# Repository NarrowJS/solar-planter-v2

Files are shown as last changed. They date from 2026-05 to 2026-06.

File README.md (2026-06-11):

# Solar Planter V2
Integrates temperature, humidity, and soil moisture sensing into a single discrete plant pot and notifies you of the plant's health using LEDs and push notifications via IOT. The pot features a solar panel on the side to slowly recharge the internal battery, removing the need for recharging the device manually.
### Features
- Zigbee and Matter connectivity for low power wireless communication
- RGB Leds for notification
- Easily removable plant pot via magnets for a modular design
- Removable temperature and humidity sensor module

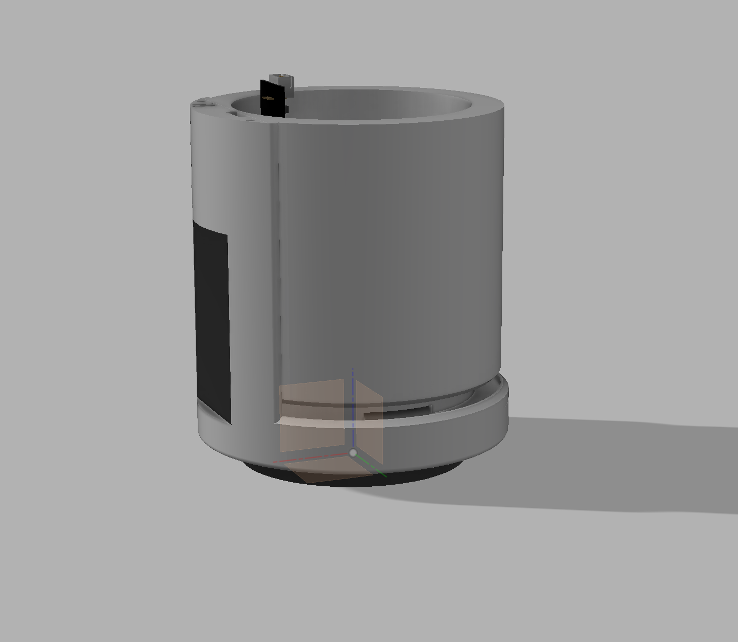
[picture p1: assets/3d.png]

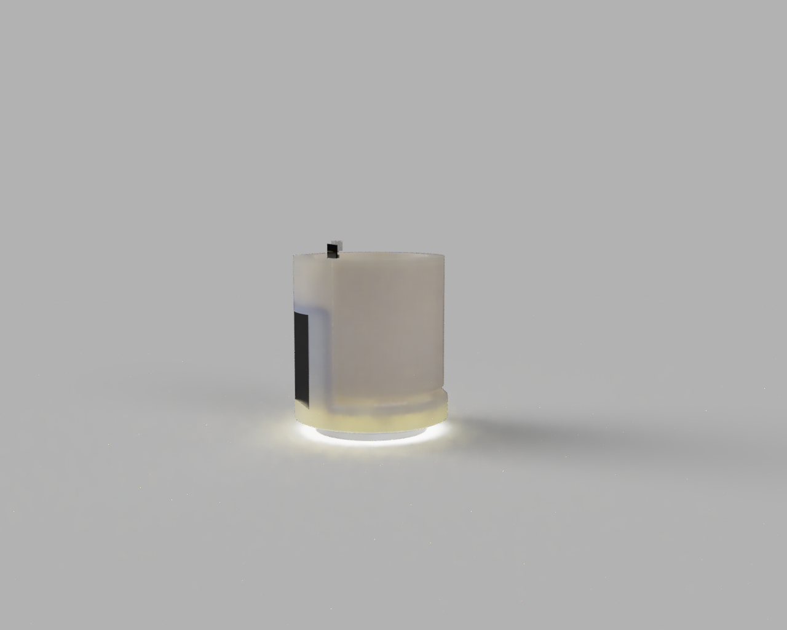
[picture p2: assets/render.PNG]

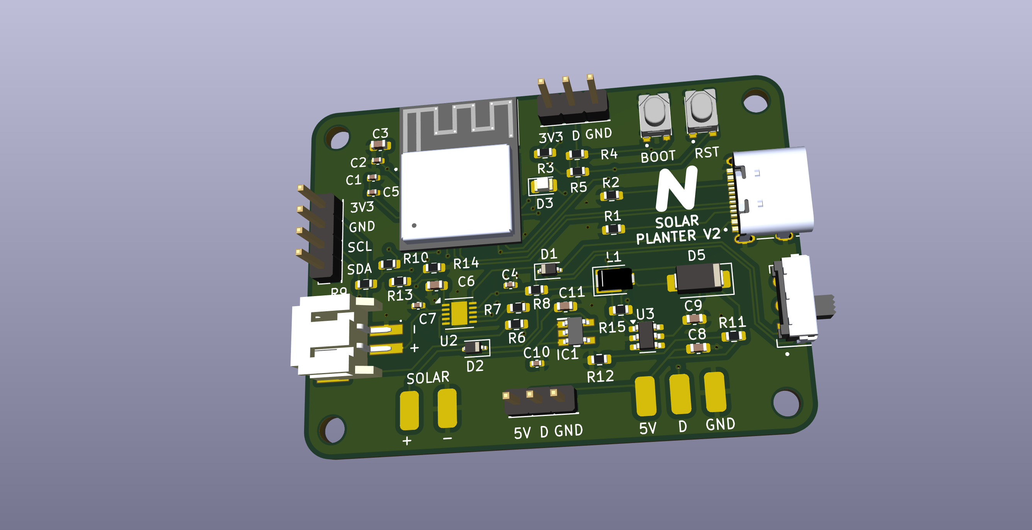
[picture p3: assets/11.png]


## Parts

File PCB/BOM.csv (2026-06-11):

Id | Designator | Footprint | Quantity | Designation | Part # | Link
1 | S1 | SW_EG1247 | 1 | EG1247 | C431548 | https://www.lcsc.com/product-detail/C431548.html
2 | D3 | LED_0805_2012Metric | 1 | CHARGE LED | C19273154 | https://www.lcsc.com/product-detail/C19273154.html
3 | C4,C5,C1,C2 | C_0402_1005Metric | 4 | 100nF | C60474 | https://www.lcsc.com/product-detail/C60474.html
4 | U1 | XCVR_ESP32-C6-MINI-1-H4 | 1 | ESP32-C6-MINI-1-H4 | C6553337 | https://www.lcsc.com/product-detail/C6553337.html
5 | 3V3 | PinHeader_1x01_P2.54mm_Vertical | 1 | MOISTURE_VCC
6 | GND | SolderWirePad_1x01_SMD_1x2mm | 1 | LED_GND
7 | R3,R4,R5,R10,R15,R8,R9,R7 | R_0603_1608Metric | 8 | 10k | C95204 | https://www.lcsc.com/product-detail/C95204.html
8 | C8,C9 | C_0603_1608Metric | 2 | 22uF | C86295 | https://www.lcsc.com/product-detail/C86295.html
9 | R6,R12 | R_0603_1608Metric | 2 | 1k | C5362357 | https://www.lcsc.com/product-detail/C5362357.html
10 | R2,R1 | R_0603_1608Metric | 2 | 5k1 | C2907044 | https://www.lcsc.com/product-detail/C2907044.html
11 | D | PinHeader_1x01_P2.54mm_Vertical | 1 | MOISTURE_DATA
12 | 5V | PinHeader_1x01_P2.54mm_Vertical | 1 | TEMP_VCC
13 | BOOT,RST | SW_PTS810_SJM_250_SMTR_LFS | 2 | PTS810_SJM_250_SMTR_LFS | C116501 | https://www.lcsc.com/product-detail/C116501.html
14 | C6,C11,C3 | C_0603_1608Metric | 3 | 10uF | C19702 | https://www.lcsc.com/product-detail/C19702.html
15 | D5 | D_SMA | 1 | SS34 | C908680 | https://www.lcsc.com/product-detail/C908680.html
16 | GND | PinHeader_1x01_P2.54mm_Vertical | 1 | TEMP_GND
17 | U3 | SOT-23-6 | 1 | MT3608 | C84817 | https://www.lcsc.com/product-detail/C84817.html
18 | C7,C10 | C_0402_1005Metric | 2 | 1uF | C29266 | https://www.lcsc.com/product-detail/C29266.html
19 | IC1 | SOT94P280X100-5N | 1 | RT9080-33GJ5 | C841192 | https://www.lcsc.com/product-detail/C841192.html
20 | + - | JST_S2B-PH-SM4-TB | 1 | S2B-PH-SM4-TB | C295747 | https://www.lcsc.com/product-detail/C295747.html
21 | D2,D1 | D_SOD-323 | 2 | 1N5819WS | C191023 | https://www.lcsc.com/product-detail/C191023.html
22 | J1 | HRO_TYPE-C-31-M-12 | 1 | TYPE-C-31-M-12 | C165948 | https://www.lcsc.com/product-detail/C165948.html
23 | + | SolderWirePad_1x01_SMD_1x2mm | 1 | +SOLAR
24 | 3V3 | PinHeader_1x01_P2.54mm_Vertical | 1 | 3V3
25 | GND | PinHeader_1x01_P2.54mm_Vertical | 1 | MOISTURE_GND
26 | SDA | PinHeader_1x01_P2.54mm_Vertical | 1 | SDA
27 | L1 | D_SMP_DO-220AA | 1 | CD32 | C41408473 | https://www.lcsc.com/product-detail/C41408473.html
28 | GND | PinHeader_1x01_P2.54mm_Vertical | 1 | LED_GND
29 | R11 | R_0603_1608Metric | 1 | 7K5 | C23234 | https://www.lcsc.com/product-detail/C23234.html
30 | D | SolderWirePad_1x01_SMD_1x2mm | 1 | LED_DATA
31 | 5V | SolderWirePad_1x01_SMD_1x2mm | 1 | LED_VCC
32 | SCL | PinHeader_1x01_P2.54mm_Vertical | 1 | SCL
33 | - | SolderWirePad_1x01_SMD_1x2mm | 1 | SOLAR-
34 | R14 | R_0603_1608Metric | 1 | 100k | C14675 | https://www.lcsc.com/product-detail/C14675.html
35 | U2 | DFN-10-1EP_3x3mm_P0.5mm_EP1.7x2.5mm | 1 | PQ25186DLHR | C44639442 | https://www.lcsc.com/product-detail/C44639442.html
36 | D | PinHeader_1x01_P2.54mm_Vertical | 1 | TEMP_DATA
37 | R13 | R_0603_1608Metric | 1 | 27k | C22967 | https://www.lcsc.com/product-detail/C22967.html

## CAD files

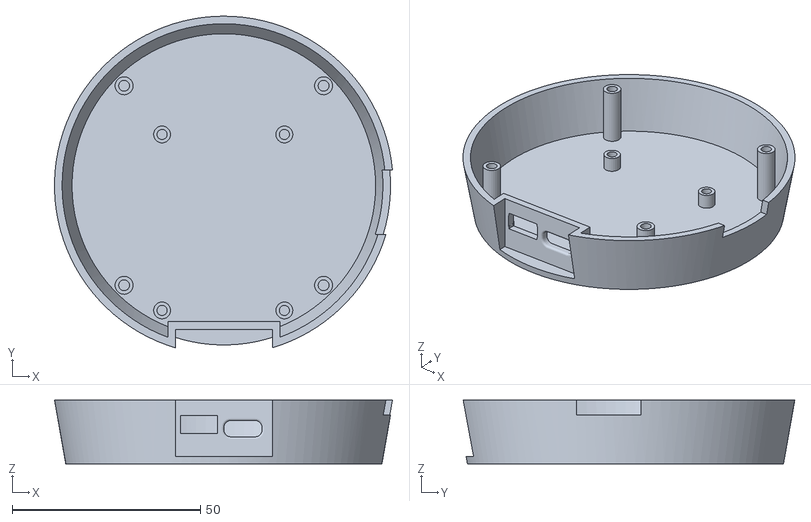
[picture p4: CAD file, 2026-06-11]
STLs/base.stl
89.8 x 88.1 x 17.0

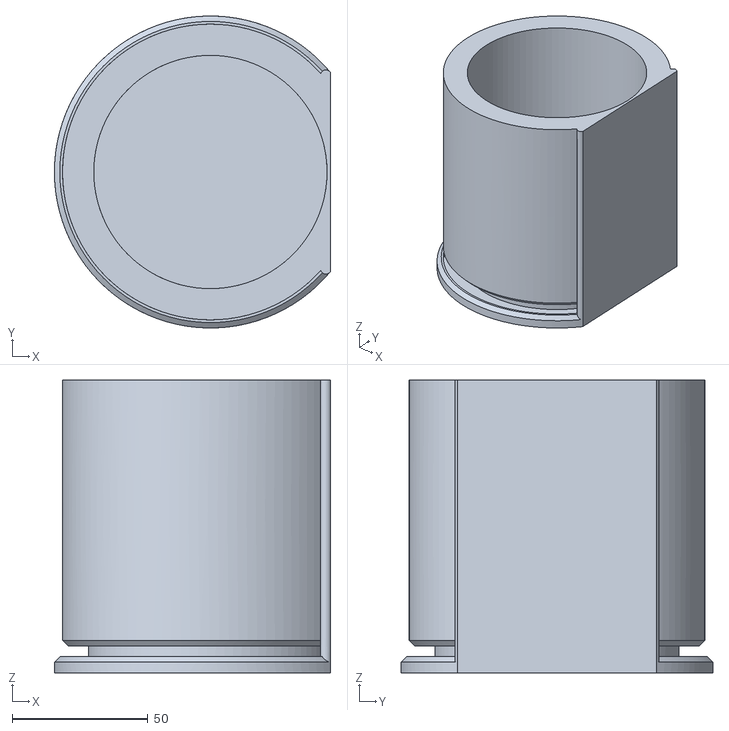
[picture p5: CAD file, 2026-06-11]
STLs/plant-pot.stl
101.8 x 115.0 x 108.0

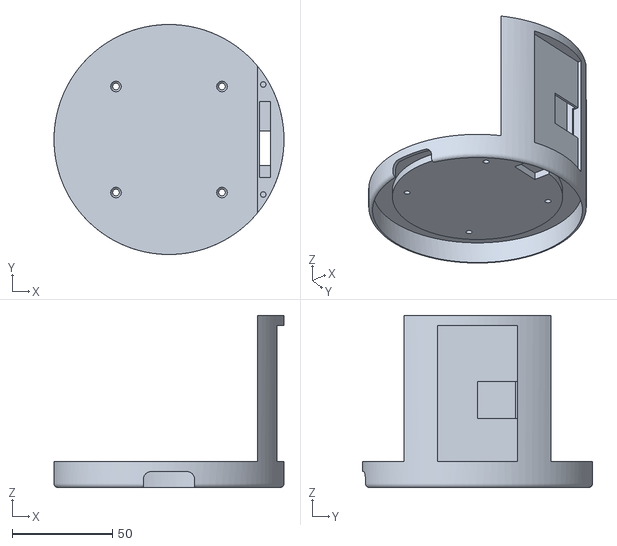
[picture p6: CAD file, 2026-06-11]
STLs/base-top.stl
115.0 x 115.0 x 86.0

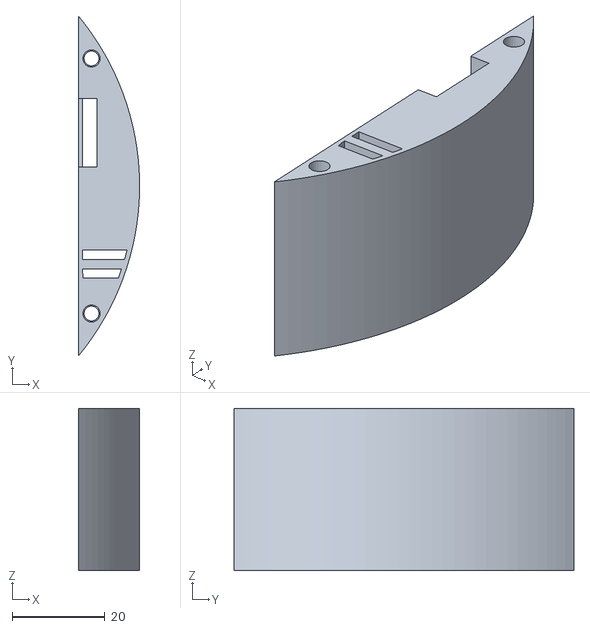
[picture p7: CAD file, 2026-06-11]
STLs/sensor-enclosure.stl
13.2 x 73.3 x 35.0

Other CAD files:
CAD/solar-planter-v2.f3z

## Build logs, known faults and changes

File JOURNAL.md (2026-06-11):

## May 17 2026

Started working on the CAD model. The goal is to make all of the electronics seperate from the planter to reduce the risk of water accidently getting into the electronics. As opposed to the LEDs in v1, I'm going to try a reflective design where the lights will bounce off the walls rather than being diffused.

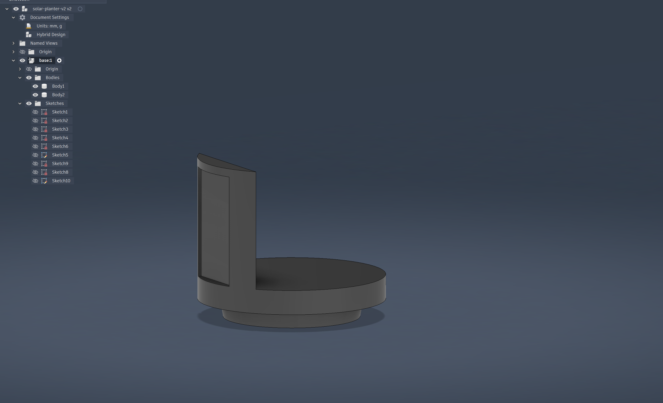
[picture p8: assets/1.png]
5/17


**Total time: 1.5 hrs**

## May 18 2026

Did some more work on the CAD model by adding a cutout for the wires from the solar panel and the moisture sensor. I was able to get rid of the cutout on the base and instead make the wires go through the bottom, where they will be almost invisible from most angles. I also started working on the PCB schematic, which will be based on the ESP32 C6-mini, giving me the ability to use zigbee instead of WiFi for the firmware.

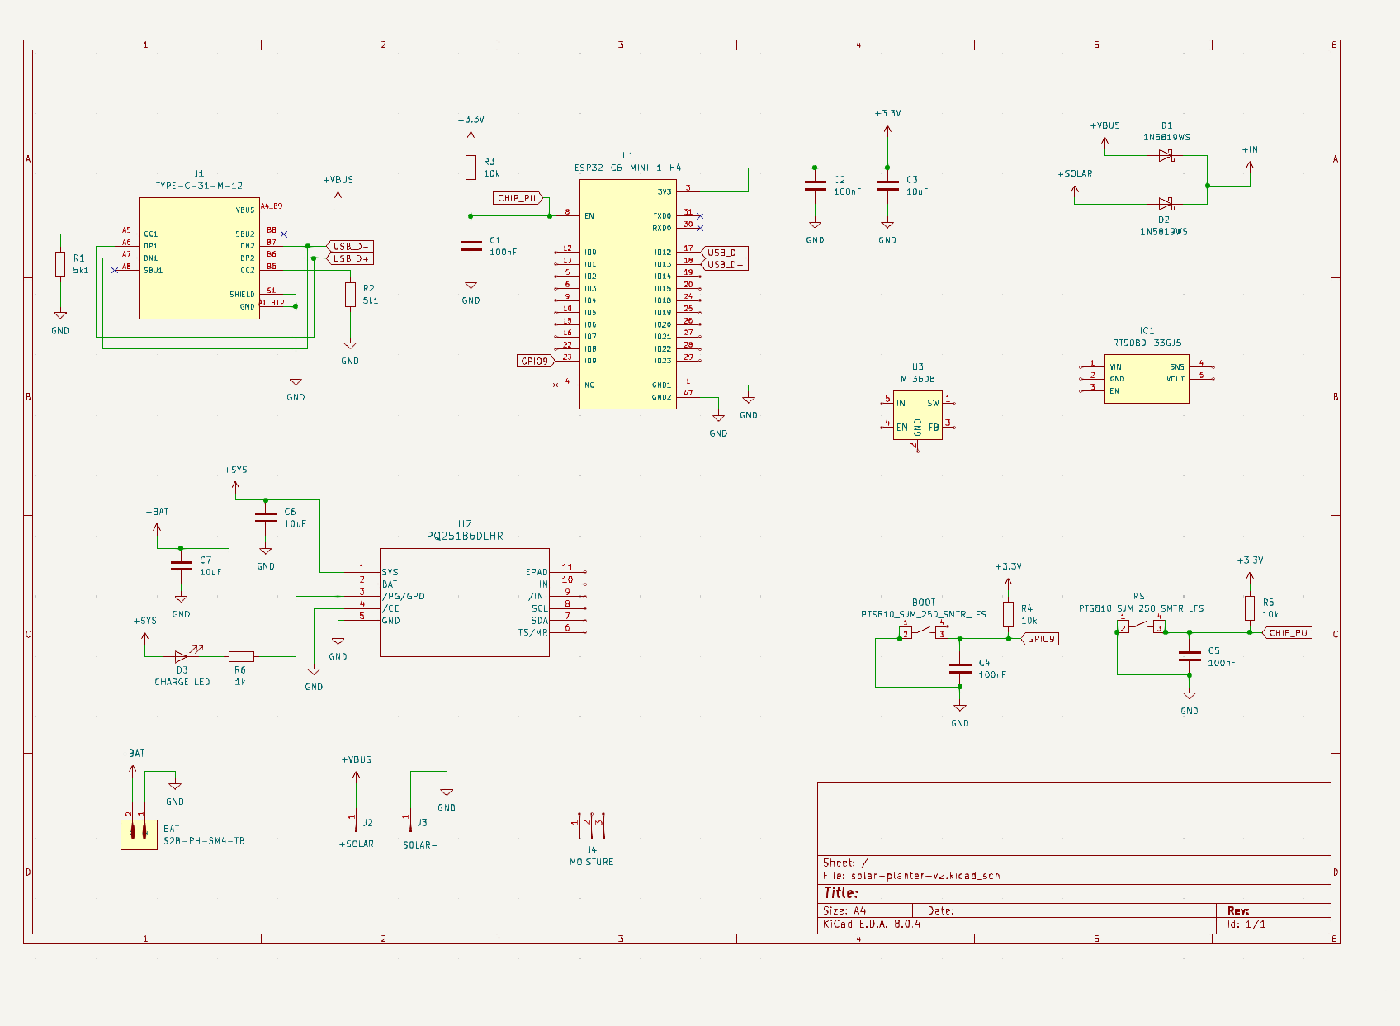
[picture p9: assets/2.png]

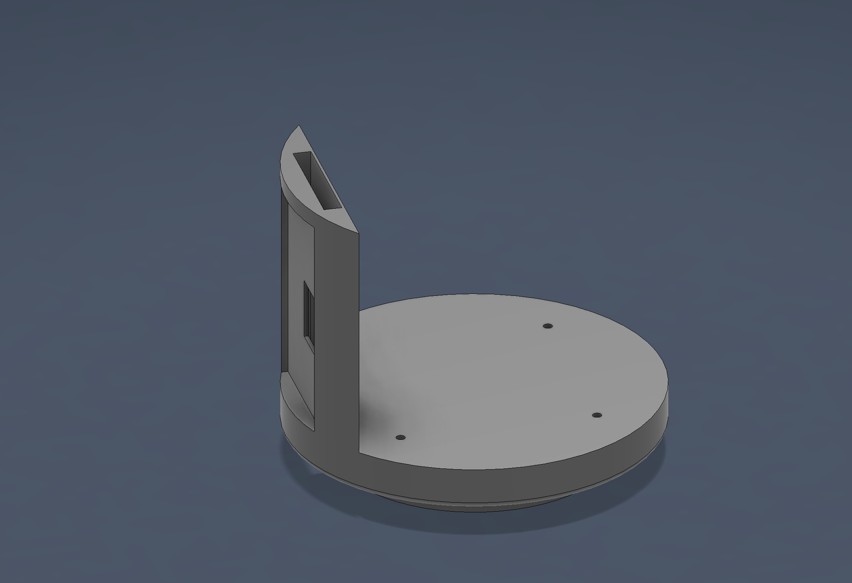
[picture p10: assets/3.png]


**Total time: 1.6 hrs**

## May 19 2026

Added in the rest of the components to the schematic and finished all of the remaining routes. I'm still not fully settled on the components and I might end up exposing some more of the wires in order to allow for easier future expansion. I'm also still not sure how much IO I want to have besides the switch and usb-c for programming, since everything else has to be done through the software at the moment.

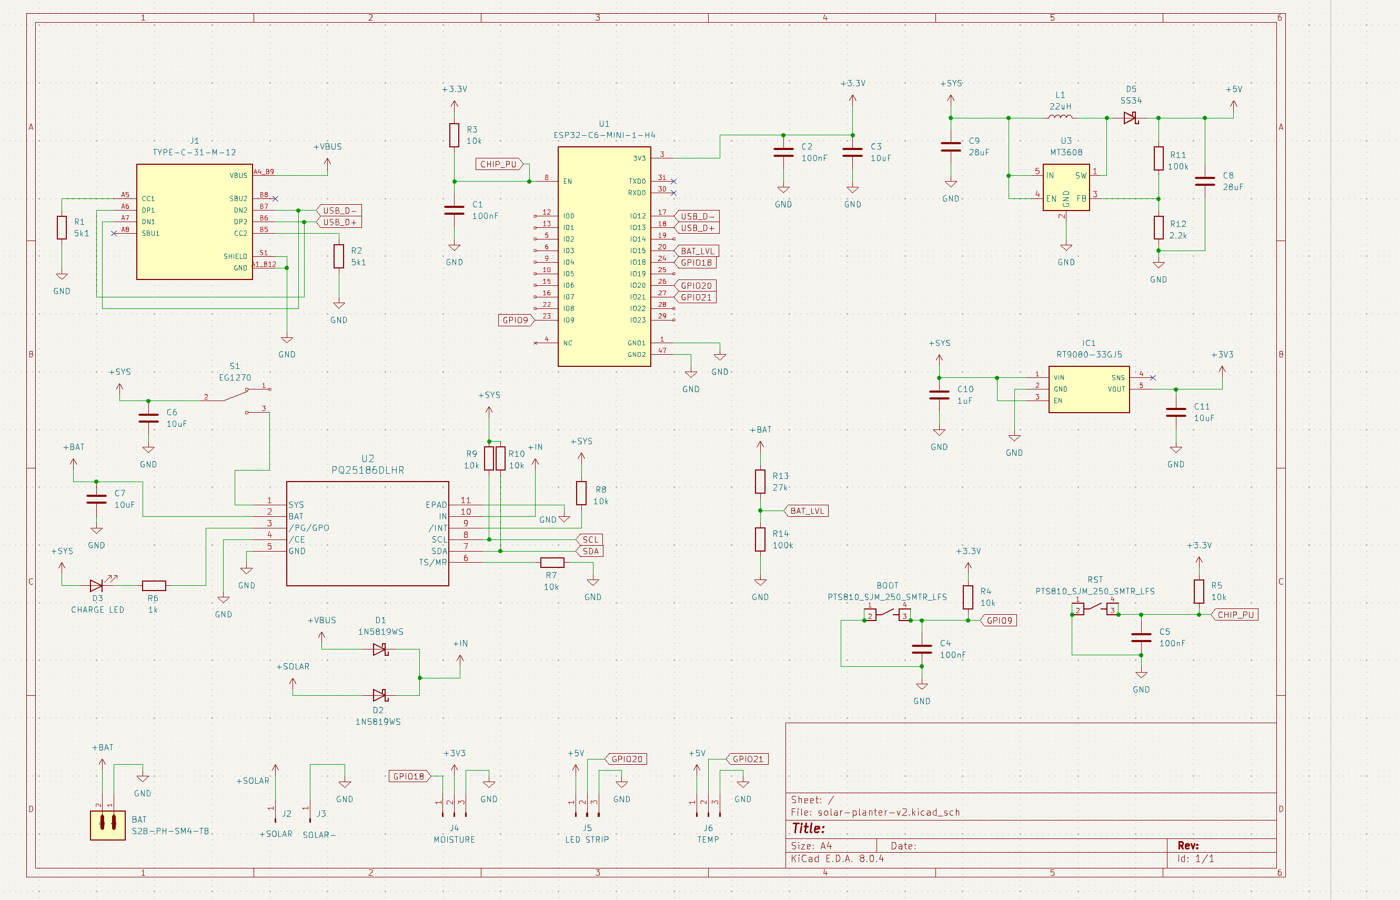
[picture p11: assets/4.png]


**Total time: 1.4 hrs**

## May 20 2026

Polished up the schematic and went over each part and compared it to the datasheet to make sure I didn't make any careless mistakes. I was able to catch a couple, the i2c pins werent connected, a couple of capacitors were too small, and the voltage divider on the boost circuit was incorrect. I also made some of the connections less confusing and reorganized the layout for readability. It's now time to route all of the traces on the pcb.

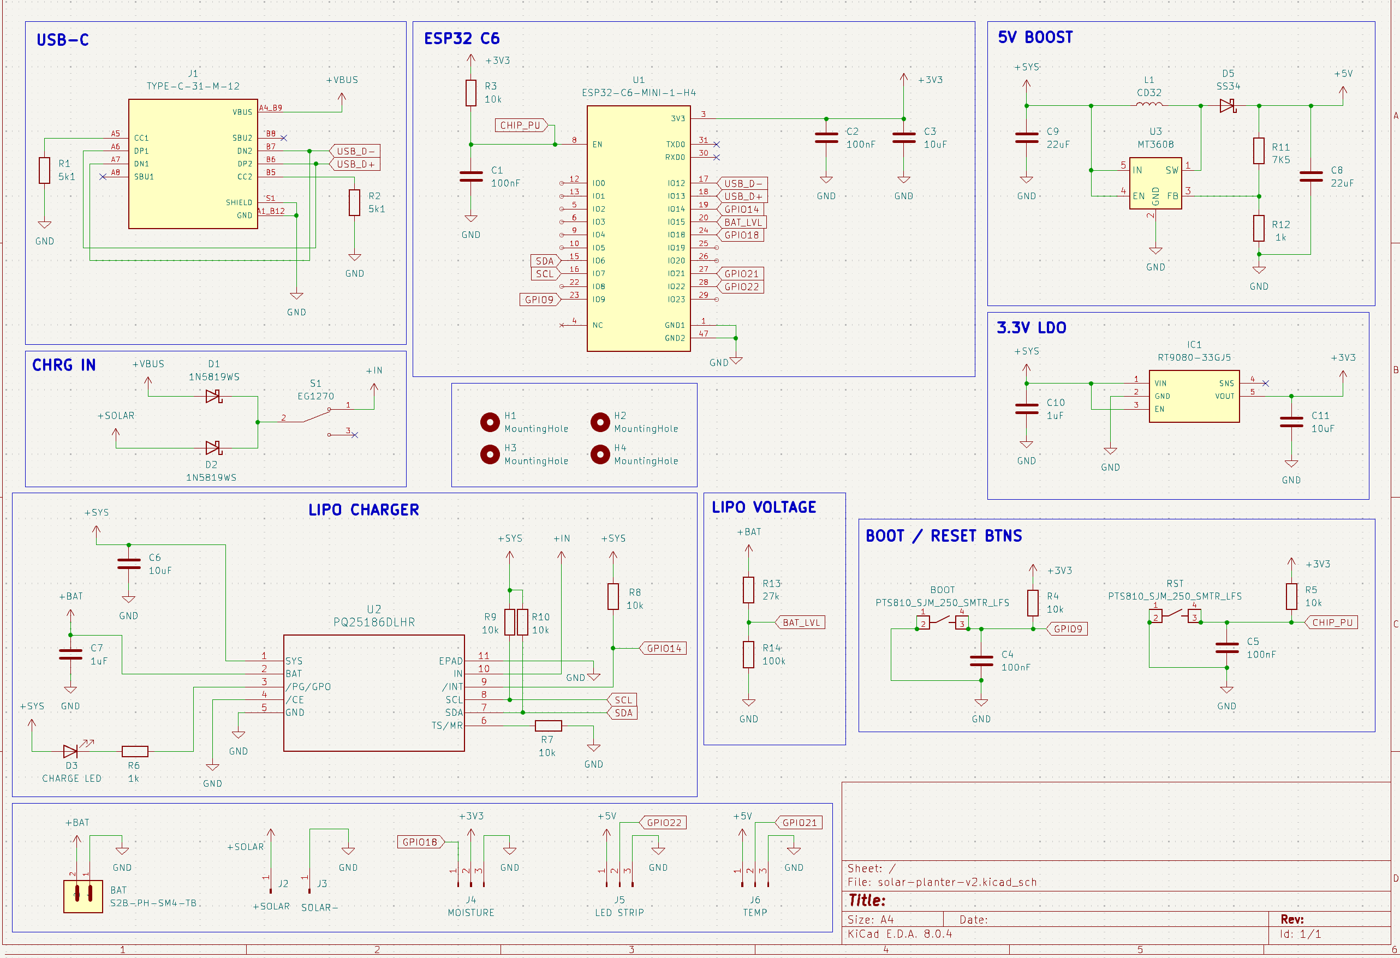
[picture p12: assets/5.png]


time: 1.5 hrs

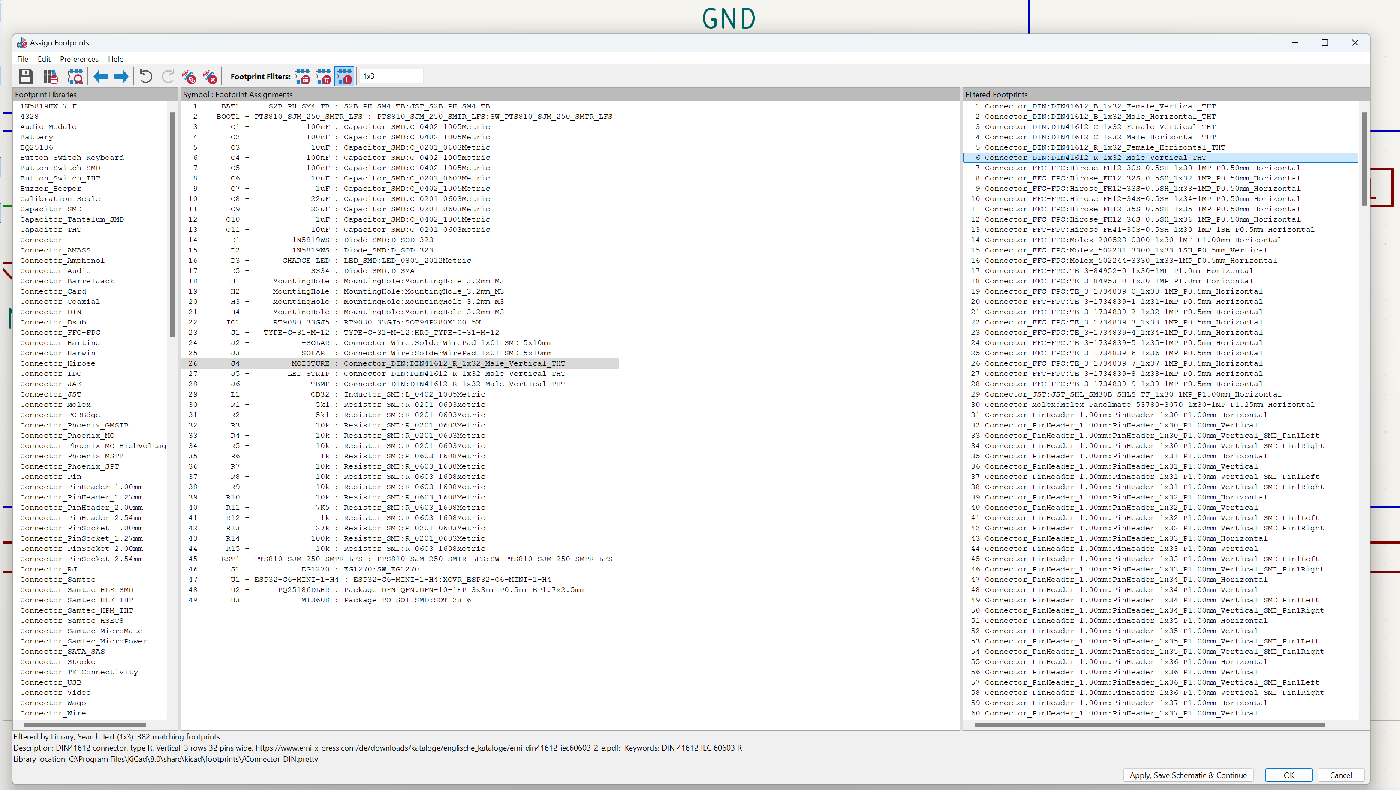
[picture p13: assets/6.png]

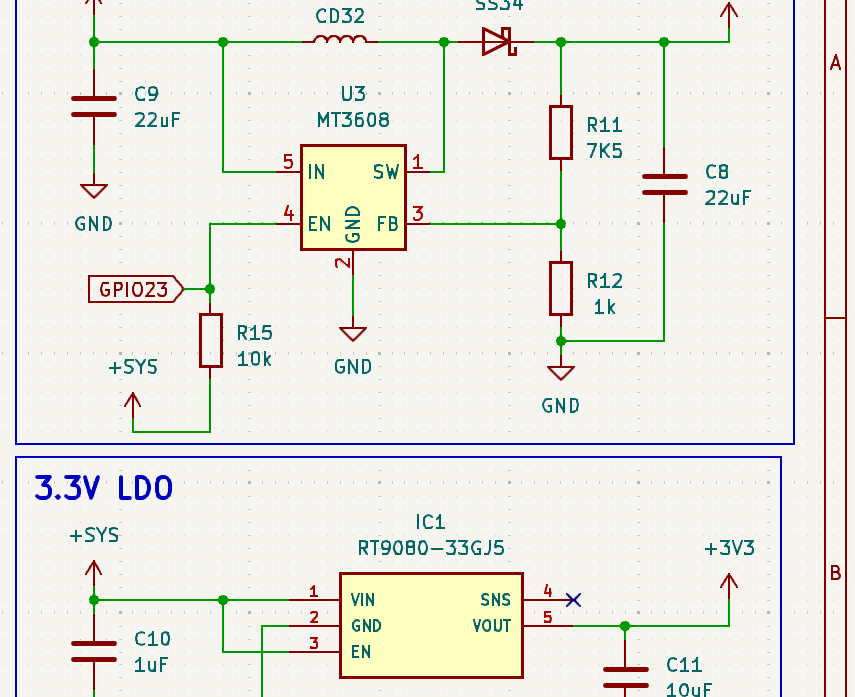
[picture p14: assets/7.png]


I decided to double check the current draw of MT3608 and found that it draws quite a bit of current even when it is idle. This would be the case for my board since I had EN hardwired to the SYS voltage wire. To improve efficiency, I added in a pull up resistor connected to a pin on the ESP32 so that I could programatically switch off the boost converter when I know that I will not need it, for ex in deep sleep. This should have a big impact on battery.

time: 0.5 hrs

**Total time: 2 hrs**

## May 21 2026

Started working on the PCB design and arranged all of the footprints so that hopefully it will be easier to route all of them. I realized that I completely messed up the footprints for the connectors and the resistors/capacitors since some of them were in 0201 size, which is way smaller than 0603. After fixing that I also had to enlarge the pads for the solar/led connection, but I decided to keep the sensors as pins since they already have dupont cables included.

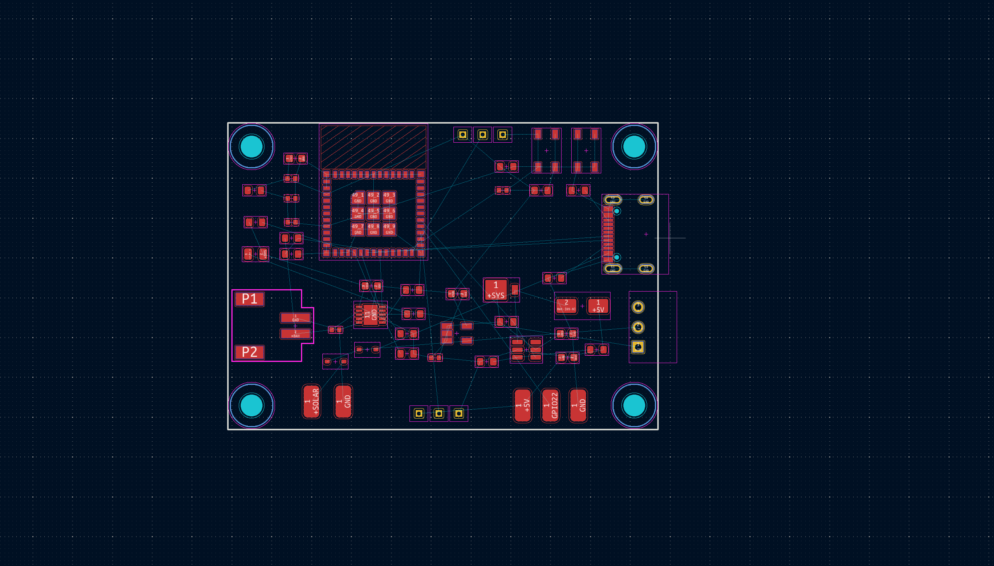
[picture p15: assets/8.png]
5/21


**Total time: 1.4 hrs**

## June 8 2026

Started routing the traces for the PCB. Before that, I added in an extra couple of pins to breakout the i2c line to make this board more versatile if I wanted to switch out the sensors some time in the future. I routed almost all of the pads that I could without switching to the back layer since I don't want to use too many unneccessary vias. I'm pretty happy with how they're looking right now and this definitely has to be one of my neatest looking boards so far.

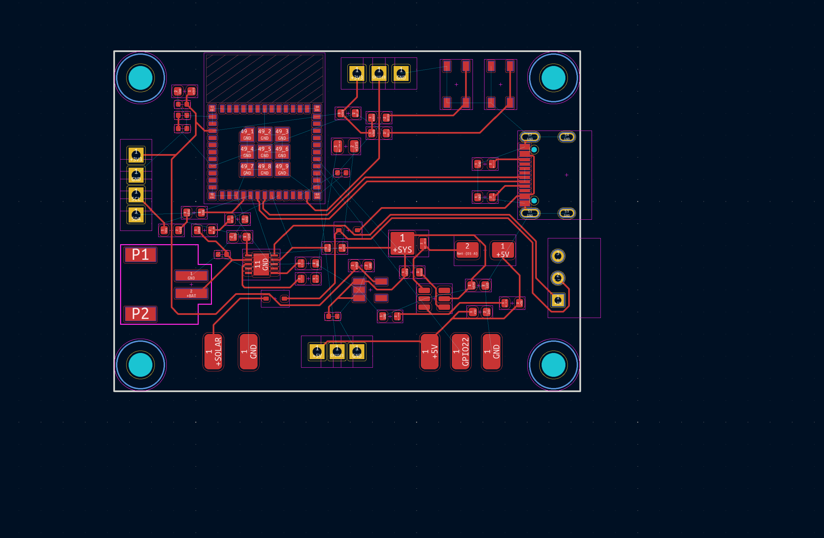
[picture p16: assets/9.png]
6/8


**Total time: 2 hrs**

## June 9 2026

Finished all of the routes for the PCB, fixed some of the silk screen, added in labels, and created the ground fill. Unfortunately there a couple of islands created via the ground fill, and I couldn't figure out how to easily fix without putting a via on the pad. Although this should be fine, this did make the board not as clean as I wanted it to be. On the flip side, I also added in some beautiful rounded corners which I plan on doing for every PCB I make from now on. Time to get the board checked and make any small modifications that might be needed.

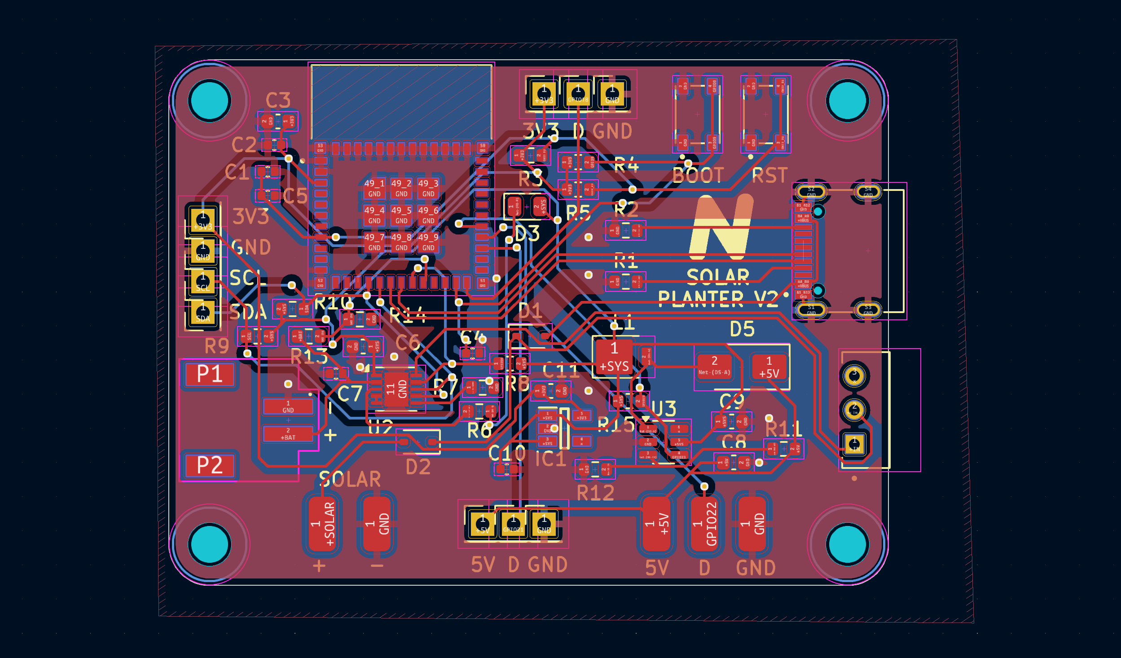
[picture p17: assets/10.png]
6/9

6/9-2

**Total time: 2.3 hrs**

After sending my PCB and schematic for some feedback, I got a suggestion to make the traces for the power lines a bit wider. So I changed all of the power carrying traces (except for the battery ones) to use 0.4mm trace widths instead of the default 0.25mm. I also added in some silk screen on the maximum input voltage for the solar panel as a safety in case I want to experiment with different panels in the future.

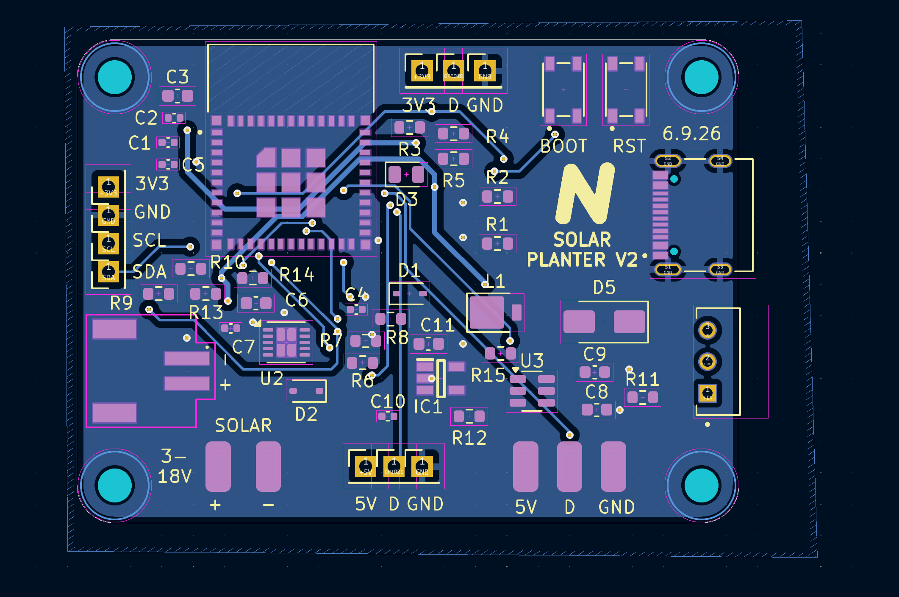
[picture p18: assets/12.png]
6/9-3

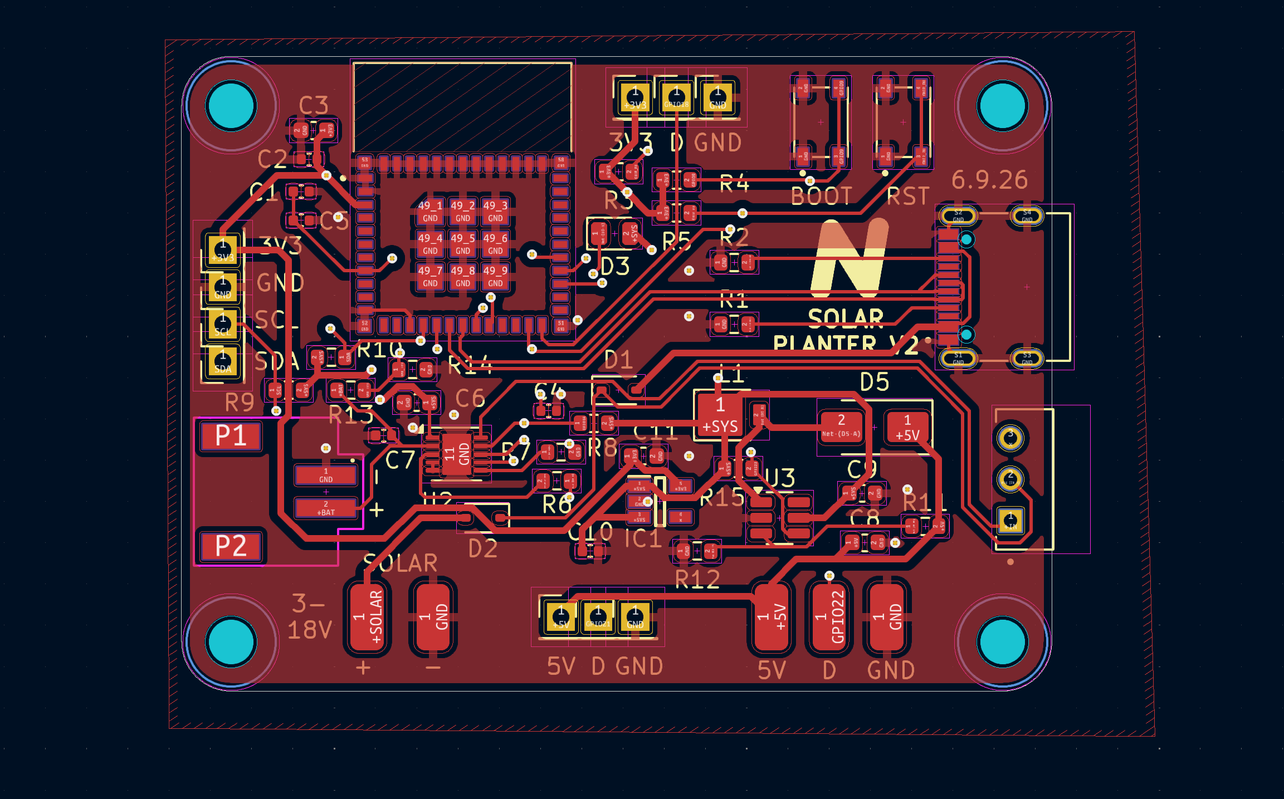
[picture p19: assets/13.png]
6/9-4


**Total time: 1 hr**

Did some more on the 3D model and added in the removable plant-pot enclosure. The plan is to have this be completely isolated from the electronics enclosure, and secure the plant-pot holder with magnets which would let you easily take it out and drain any water that gets collected in the bottom. It will also have the benefit of added customizability, since it would be easy to tweak the holder for smaller pots.

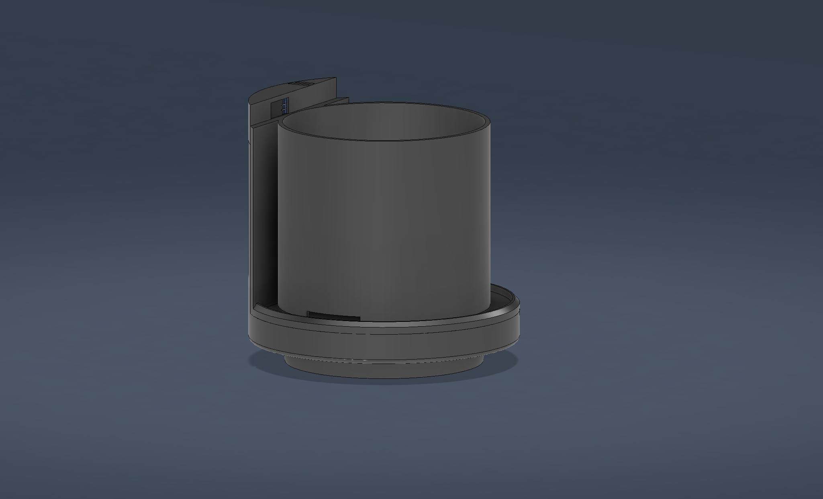
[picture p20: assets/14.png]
6/9-5


**Total time: 1.6 hr**

Polished up the 3D model and added in some missing features such as the holes for the m3 bolts to mount the top of the base to the bottom along with the cut outs for the ports to access the pcb's switch and usb-c port. I also changed the plant pot holder to look more aesthetically pleasing. Althouugh the second wall on the outside will use up more material, I think it makes the build look much more polished than before. I also added some screw holes to connect the sensor enclosure, which will have to be assembled seperately from the rest of the enclosure.

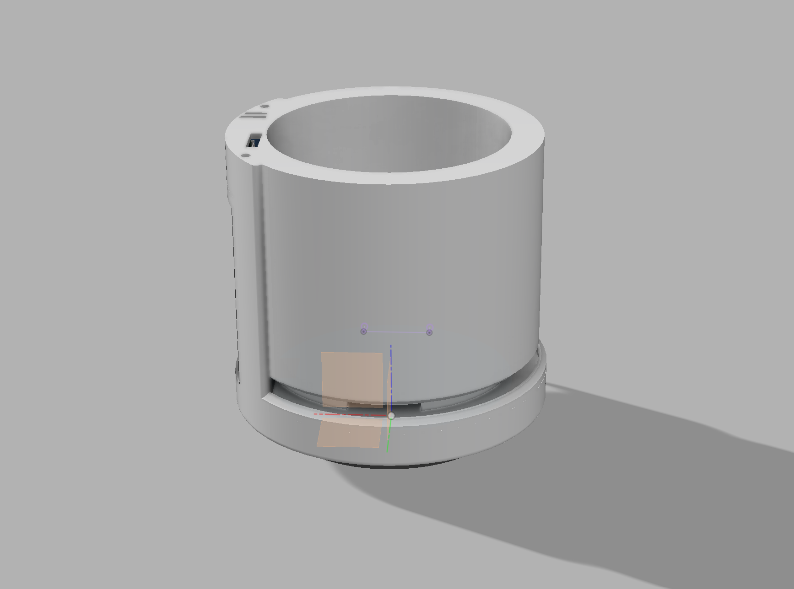
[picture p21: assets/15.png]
6/10-1

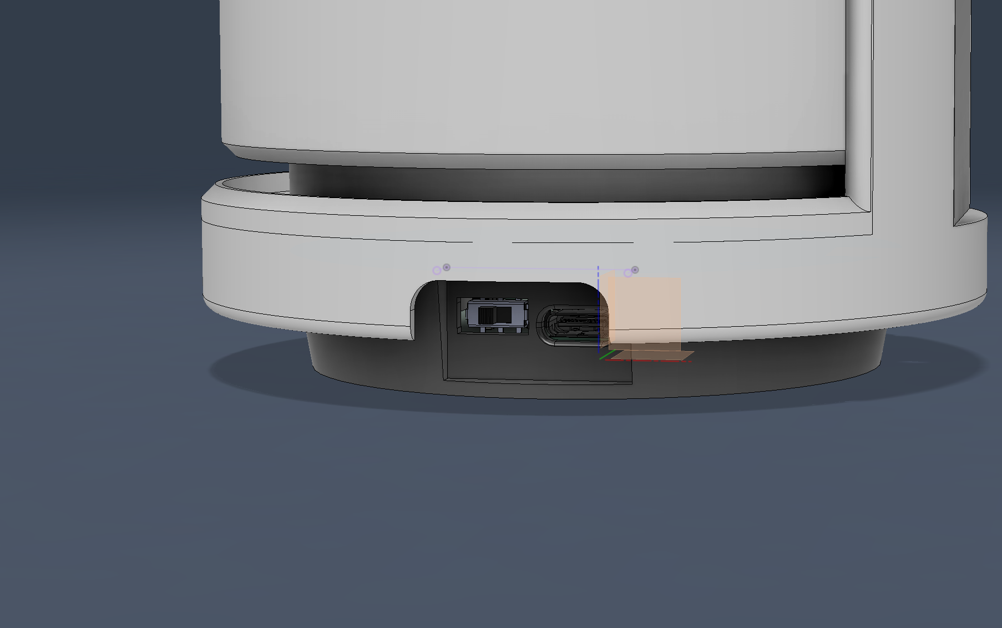
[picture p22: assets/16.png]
6/10-2

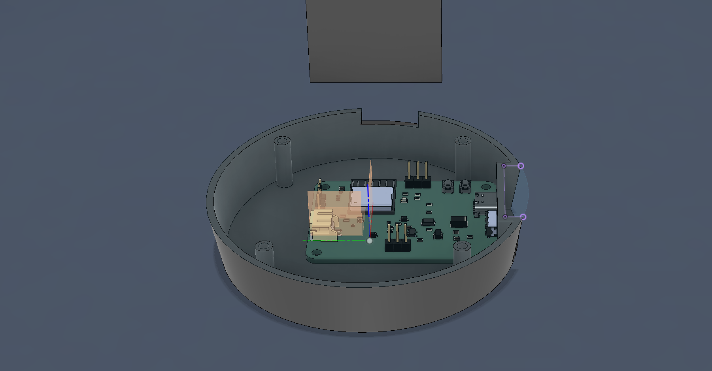
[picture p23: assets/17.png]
6/10-3


**Total time: 2.5 hrs**

Finally finished the 3D model. I went over all of the screw holes and fixed some of the sizing, since for some of the holes the diameter was too small to fit the m3 bolts I'm planning on using. I also added some stand offs to mount the PCB with and created the cutouts for the magnets that I will insert into the enclosure halfway during the 3d print, this way they will be hidden and securely fit into place. Lastly, I increased the height of the overall pot to accomodate the standard plant holder that I have.

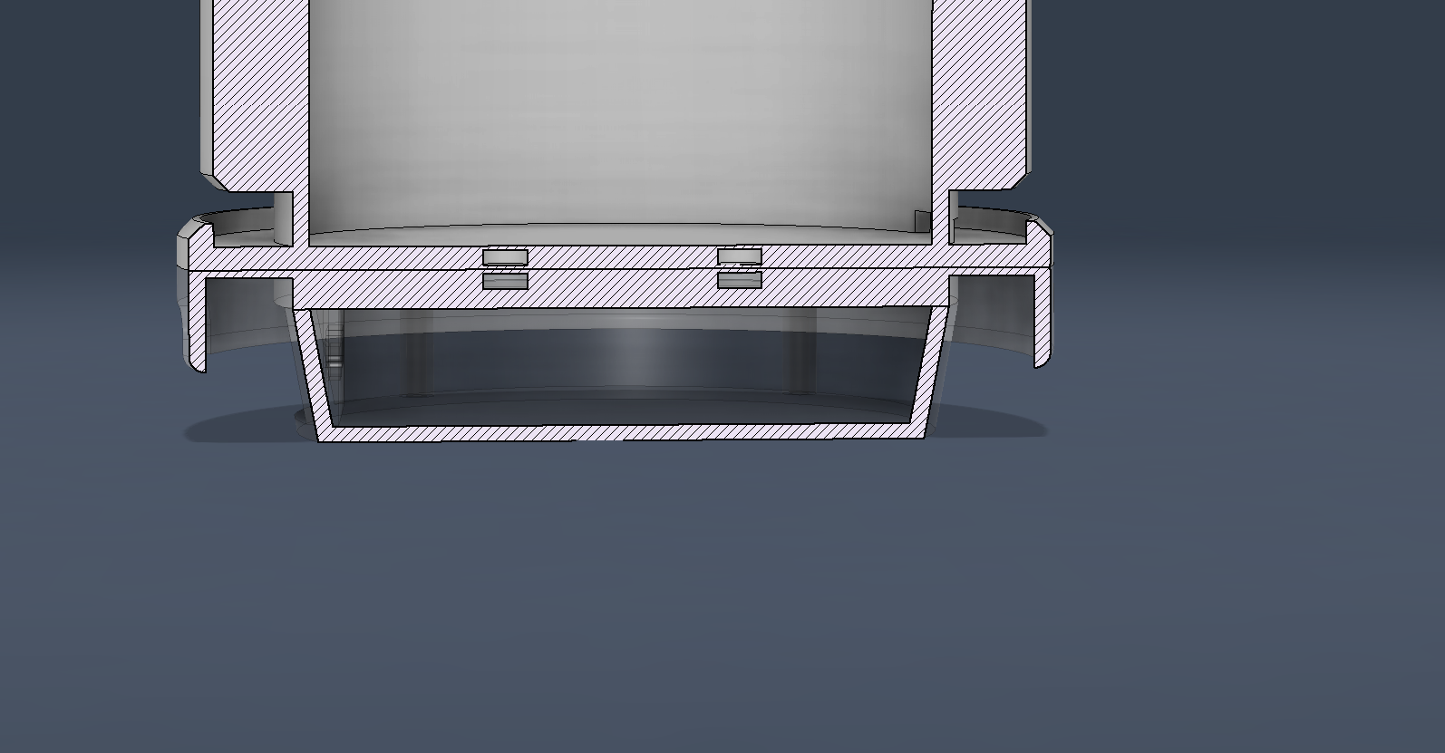
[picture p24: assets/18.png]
6/11-1

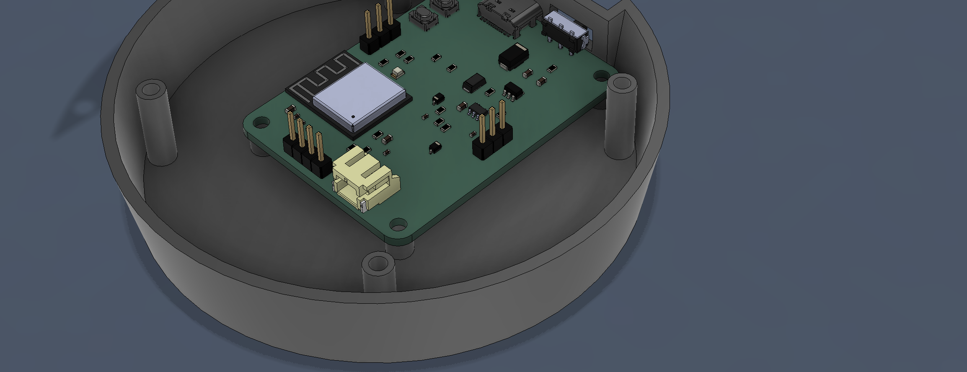
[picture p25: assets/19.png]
6/11-2

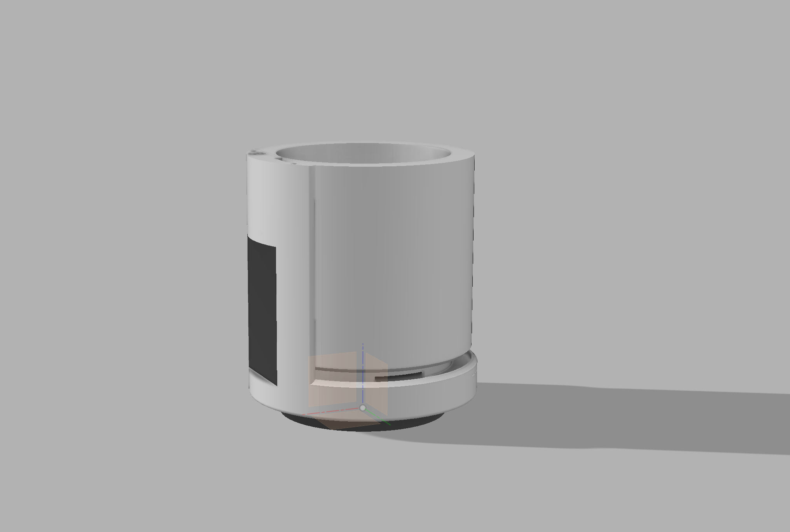
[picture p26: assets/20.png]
6/11-3


**Total time: 1.2 hrs**

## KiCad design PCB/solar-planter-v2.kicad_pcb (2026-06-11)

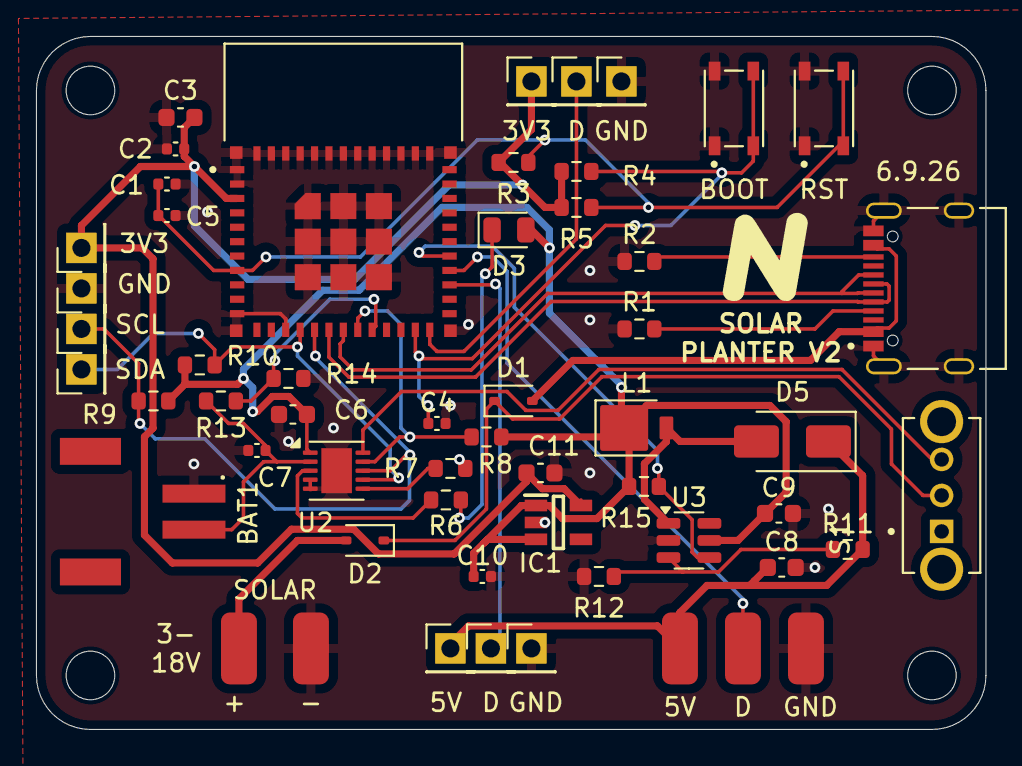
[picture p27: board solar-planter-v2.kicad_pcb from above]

Board: 2 copper layers, 52.8 x 38.5 mm, 59 parts (0 on the bottom side), 28 nets.

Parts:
3V3: MOISTURE_VCC; PinHeader_1x01_P2.54mm_Vertical
3V3#2: 3V3; PinHeader_1x01_P2.54mm_Vertical
5V: TEMP_VCC; PinHeader_1x01_P2.54mm_Vertical
5V#2: LED_VCC; SolderWirePad_1x01_SMD_1x2mm
+: +SOLAR; SolderWirePad_1x01_SMD_1x2mm
-: SOLAR-; SolderWirePad_1x01_SMD_1x2mm
BAT1: S2B-PH-SM4-TB; JST_S2B-PH-SM4-TB
BOOT: PTS810_SJM_250_SMTR_LFS; SW_PTS810_SJM_250_SMTR_LFS
C1, C2, C4, C5: 100nF; C_0402_1005Metric
C3, C6, C11: 10uF; C_0603_1608Metric
C7, C10: 1uF; C_0402_1005Metric
C8, C9: 22uF; C_0603_1608Metric
D: MOISTURE_DATA; PinHeader_1x01_P2.54mm_Vertical
D1, D2: 1N5819WS; D_SOD-323
D3: CHARGE LED; LED_0805_2012Metric
D5: SS34; D_SMA
D#2: LED_DATA; SolderWirePad_1x01_SMD_1x2mm
D#3: TEMP_DATA; PinHeader_1x01_P2.54mm_Vertical
GND: LED_GND; SolderWirePad_1x01_SMD_1x2mm
GND#2: TEMP_GND; PinHeader_1x01_P2.54mm_Vertical
GND#3: MOISTURE_GND; PinHeader_1x01_P2.54mm_Vertical
GND#4: LED_GND; PinHeader_1x01_P2.54mm_Vertical
H1, H2, H3, H4: MountingHole; MountingHole_2.7mm_M2.5
IC1: RT9080-33GJ5; SOT94P280X100-5N
J1: TYPE-C-31-M-12; HRO_TYPE-C-31-M-12
L1: CD32; D_SMP_DO-220AA
R1, R2: 5k1; R_0603_1608Metric
R3, R4, R5, R7, R8, R9, R10, R15: 10k; R_0603_1608Metric
R6, R12: 1k; R_0603_1608Metric
R11: 7K5; R_0603_1608Metric
R13: 27k; R_0603_1608Metric
R14: 100k; R_0603_1608Metric
RST: PTS810_SJM_250_SMTR_LFS; SW_PTS810_SJM_250_SMTR_LFS
S1: EG1247; SW_EG1247
SCL: SCL; PinHeader_1x01_P2.54mm_Vertical
SDA: SDA; PinHeader_1x01_P2.54mm_Vertical
U1: ESP32-C6-MINI-1-H4; XCVR_ESP32-C6-MINI-1-H4
U2: PQ25186DLHR; DFN-10-1EP_3x3mm_P0.5mm_EP1.7x2.5mm
U3: MT3608; SOT-23-6

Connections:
+3V3: 3V3.1, 3V3#2.1, C2.1, C3.1, C11.1, IC1.5 (VOUT), R3.1, R4.1, R5.1, U1.3 (3V3)
+5V: 5V.1, 5V#2.1, C8.1, D5.1 (K), R11.2
+BAT: BAT1.2, C7.1, R13.1, U2.2 (BAT)
+IN: S1.3, U2.10 (IN)
+SOLAR: +.1, D2.2 (A)
+SYS: C6.1, C9.1, C10.1, D3.2 (A), IC1.1 (VIN), IC1.3 (EN), L1.1, R8.2, R9.2, R10.2, R15.1, U2.1 (SYS), U3.5 (IN)
+VBUS: D1.2 (A), J1.A4_B9 (VBUS), J1.B4_A9 (VBUS)
BAT_LVL: R13.2, R14.1, U1.20 (IO15)
CHIP_PU: C1.1, C5.1, R3.2, R5.2, RST.3, RST.4, U1.8 (EN)
GND: -.1, BAT1.1, BOOT.1, BOOT.2, C1.2, C2.2, C3.2, C4.2, C5.2, C6.2, C7.2, C8.2, C9.2, C10.2, C11.2, GND.1, GND#2.1, GND#3.1, GND#4.1, IC1.2 (GND), J1.A1_B12 (GND), J1.B1_A12 (GND), J1.S1 (SHIELD), J1.S2 (SHIELD), J1.S3 (SHIELD), J1.S4 (SHIELD), R1.1, R2.1, R7.2, R12.1, R14.2, RST.1, RST.2, U1.1 (GND1), U1.2 (GND1), U1.11 (GND1), U1.14 (GND1), U1.36 (GND1), U1.37 (GND1), U1.38 (GND1), U1.39 (GND1), U1.40 (GND1), U1.41 (GND1), U1.42 (GND1), U1.43 (GND1), U1.44 (GND1), U1.45 (GND1), U1.46 (GND1), U1.47 (GND2), U1.48 (GND2), U1.49_1 (GND2), U1.49_2 (GND2), U1.49_3 (GND2), U1.49_4 (GND2), U1.49_5 (GND2), U1.49_6 (GND2), U1.49_7 (GND2), U1.49_8 (GND2), U1.49_9 (GND2), U1.50 (GND2), U1.51 (GND2), U1.52 (GND2), U1.53 (GND2), U2.4 (/CE), U2.5 (GND), U2.11 (EPAD), U3.2 (GND)
GPIO9: BOOT.3, BOOT.4, C4.1, R4.2, U1.23 (IO9)
GPIO14: R8.1, U1.19 (IO14), U2.9 (/INT)
GPIO18: D.1, U1.24 (IO18)
GPIO21: D#3.1, U1.27 (IO21)
GPIO22: D#2.1, U1.28 (IO22)
GPIO23: R15.2, U1.29 (IO23), U3.4 (EN)
unnamed: D1.1 (K), D2.1 (K), S1.2
unnamed: D3.1 (K), R6.1
unnamed: D5.2 (A), L1.2, U3.1 (SW)
unnamed: J1.A5 (CC1), R1.2
unnamed: J1.B5 (CC2), R2.2
unnamed: R7.1, U2.6 (TS/MR)
unnamed: R6.2, U2.3 (/PG/GPO)
unnamed: R11.1, R12.2, U3.3 (FB)
SCL: R9.1, SCL.1, U1.16 (IO7), U2.8 (SCL)
SDA: R10.1, SDA.1, U1.15 (IO6), U2.7 (SDA)
USB_D+: J1.A6 (DP1), J1.B6 (DP2), U1.18 (IO13)
USB_D-: J1.A7 (DN1), J1.B7 (DN2), U1.17 (IO12)

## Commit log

2026-06-09 finished PCB design
2026-06-09 fix trace widths
2026-06-09 Add removable pot enclosure
